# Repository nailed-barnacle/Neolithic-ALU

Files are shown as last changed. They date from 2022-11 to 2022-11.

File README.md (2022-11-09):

# Neolithic-ALU
This is a simple 8-bit ALU based on Ken Shirriff's dissection of the 8085's ALU at https://www.righto.com/2013/01/inside-alu-of-8085-microprocessor.html

It takes two inputs - A and B - and a number of control inputs to provide an output, one of:
- A (bypass)
- A OR B
- A AND B
- A XOR B
- A plus B with carry
- A minus B with carry 
- Complement of B
- A shifted right

Notes:

The carry input and output for arithmetic operations is inverted. To add or subtract without carry, it must be set. For other logic operations it must be set or cleared.

The zero output is inverted (i.e. set if the output is not zero).

The sign output is simply bit 7 of the result.

The bit shifted out after a right shift is the lowest input bit; it has no dedicated output. A dedicated input - shift_in - provides the high bit of the shift result.

At the time of posting, the only parts available for all components were 74HC; the circuit will operate across the 74HC range but will be faster at 5v than 3v3. I still need to measure the propagation delay but expect it to be around 60-70ns at five volts. Other equivalant parts - e.g. AHC or VLC - will probably be faster. The critical path is the chain of OR gates running right to left through the circuit.

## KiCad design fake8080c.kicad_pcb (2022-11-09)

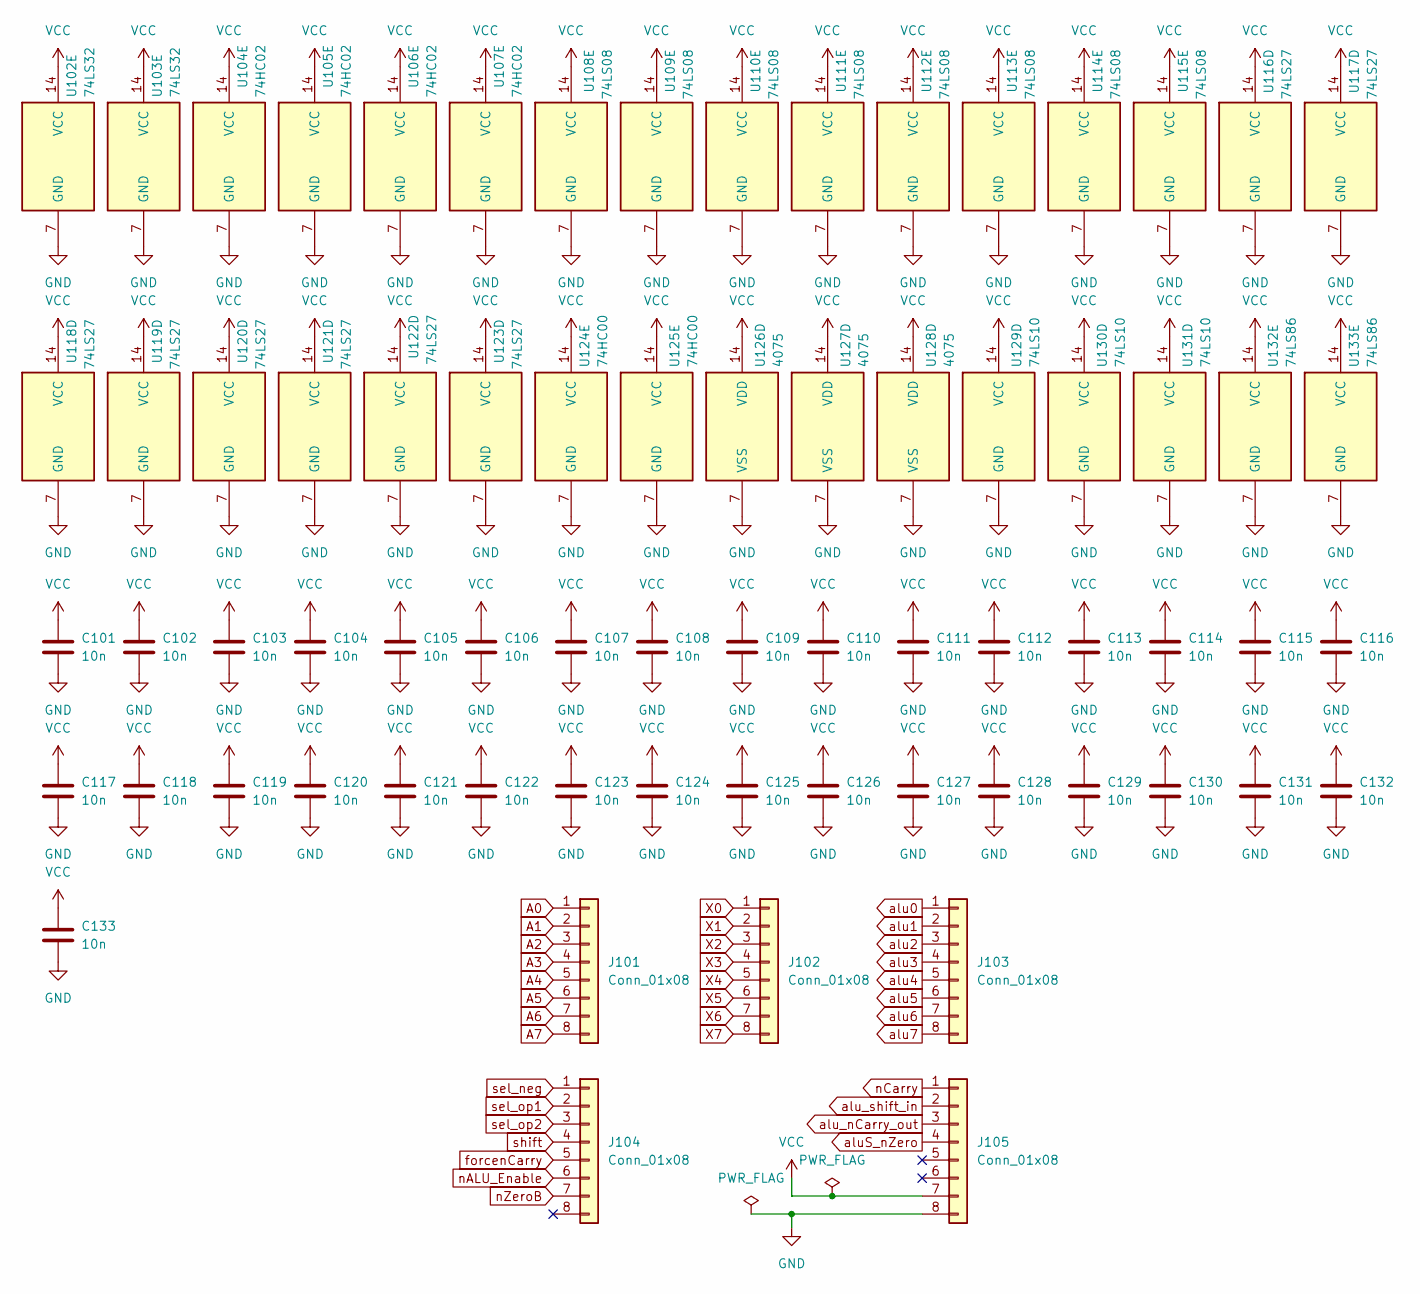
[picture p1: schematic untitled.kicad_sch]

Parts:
C101, C102, C103, C104, C105, C106, C107, C108, C109, C110, C111, C112, C113, C114, C115, C116, C117, C118, C119, C120, C121, C122, C123, C124, C125, C126, C127, C128, C129, C130, C131, C132, C133: 10n; C_0603_1608Metric
J101, J102, J103, J104, J105: Conn_01x08; PinHeader_1x08_P2.54mm_Vertical
U102, U103: 74LS32; SOIC-14_3.9x8.7mm_P1.27mm
U104, U105, U106, U107: 74HC02; SOIC-14_3.9x8.7mm_P1.27mm
U108, U109, U110, U111, U112, U113, U114, U115: 74LS08; SOIC-14_3.9x8.7mm_P1.27mm
U116, U117, U118, U119, U120, U121, U122, U123: 74LS27; SOIC-14_3.9x8.7mm_P1.27mm
U124, U125: 74HC00; SOIC-14_3.9x8.7mm_P1.27mm
U126, U127, U128: 4075; SOIC-14_3.9x8.7mm_P1.27mm
U129, U130, U131: 74LS10; SOIC-14_3.9x8.7mm_P1.27mm
U132, U133: 74LS86; SOIC-14_3.9x8.7mm_P1.27mm

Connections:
A0: J101.1; also elsewhere on the board
A1: J101.2; also elsewhere on the board
A2: J101.3; also elsewhere on the board
A3: J101.4; also elsewhere on the board
A4: J101.5; also elsewhere on the board
A5: J101.6; also elsewhere on the board
A6: J101.7; also elsewhere on the board
A7: J101.8; also elsewhere on the board
GND: C101.2, C102.2, C103.2, C104.2, C105.2, C106.2, C107.2, C108.2, C109.2, C110.2, C111.2, C112.2, C113.2, C114.2, C115.2, C116.2, C117.2, C118.2, C119.2, C120.2, C121.2, C122.2, C123.2, C124.2, C125.2, C126.2, C127.2, C128.2, C129.2, C130.2, C131.2, C132.2, C133.2, J105.8, U102.7 (GND), U103.7 (GND), U104.7 (GND), U105.7 (GND), U106.7 (GND), U107.7 (GND), U108.7 (GND), U109.7 (GND), U110.7 (GND), U111.7 (GND), U112.7 (GND), U113.7 (GND), U114.7 (GND), U115.7 (GND), U116.7 (GND), U117.7 (GND), U118.7 (GND), U119.7 (GND), U120.7 (GND), U121.7 (GND), U122.7 (GND), U123.7 (GND), U124.7 (GND), U125.7 (GND), U126.7 (VSS), U127.7 (VSS), U128.7 (VSS), U129.7 (GND), U130.7 (GND), U131.7 (GND), U132.7 (GND), U133.7 (GND); also elsewhere on the board
VCC: C101.1, C102.1, C103.1, C104.1, C105.1, C106.1, C107.1, C108.1, C109.1, C110.1, C111.1, C112.1, C113.1, C114.1, C115.1, C116.1, C117.1, C118.1, C119.1, C120.1, C121.1, C122.1, C123.1, C124.1, C125.1, C126.1, C127.1, C128.1, C129.1, C130.1, C131.1, C132.1, C133.1, J105.7, U102.14 (VCC), U103.14 (VCC), U104.14 (VCC), U105.14 (VCC), U106.14 (VCC), U107.14 (VCC), U108.14 (VCC), U109.14 (VCC), U110.14 (VCC), U111.14 (VCC), U112.14 (VCC), U113.14 (VCC), U114.14 (VCC), U115.14 (VCC), U116.14 (VCC), U117.14 (VCC), U118.14 (VCC), U119.14 (VCC), U120.14 (VCC), U121.14 (VCC), U122.14 (VCC), U123.14 (VCC), U124.14 (VCC), U125.14 (VCC), U126.14 (VDD), U127.14 (VDD), U128.14 (VDD), U129.14 (VCC), U130.14 (VCC), U131.14 (VCC), U132.14 (VCC), U133.14 (VCC); also elsewhere on the board
X0: J102.1; also elsewhere on the board
X1: J102.2; also elsewhere on the board
X2: J102.3; also elsewhere on the board
X3: J102.4; also elsewhere on the board
X4: J102.5; also elsewhere on the board
X5: J102.6; also elsewhere on the board
X6: J102.7; also elsewhere on the board
X7: J102.8; also elsewhere on the board
alu0: J103.1; also elsewhere on the board
alu1: J103.2; also elsewhere on the board
alu2: J103.3; also elsewhere on the board
alu3: J103.4; also elsewhere on the board
alu4: J103.5; also elsewhere on the board
alu5: J103.6; also elsewhere on the board
alu6: J103.7; also elsewhere on the board
alu7: J103.8; also elsewhere on the board
aluS_nZero: J105.4; also elsewhere on the board
alu_nCarry_out: J105.3; also elsewhere on the board
alu_shift_in: J105.2; also elsewhere on the board
forcenCarry: J104.5; also elsewhere on the board
nALU_Enable: J104.6; also elsewhere on the board
nCarry: J105.1; also elsewhere on the board
nZeroB: J104.7; also elsewhere on the board
sel_neg: J104.1; also elsewhere on the board
sel_op1: J104.2; also elsewhere on the board
sel_op2: J104.3; also elsewhere on the board
shift: J104.4; also elsewhere on the board

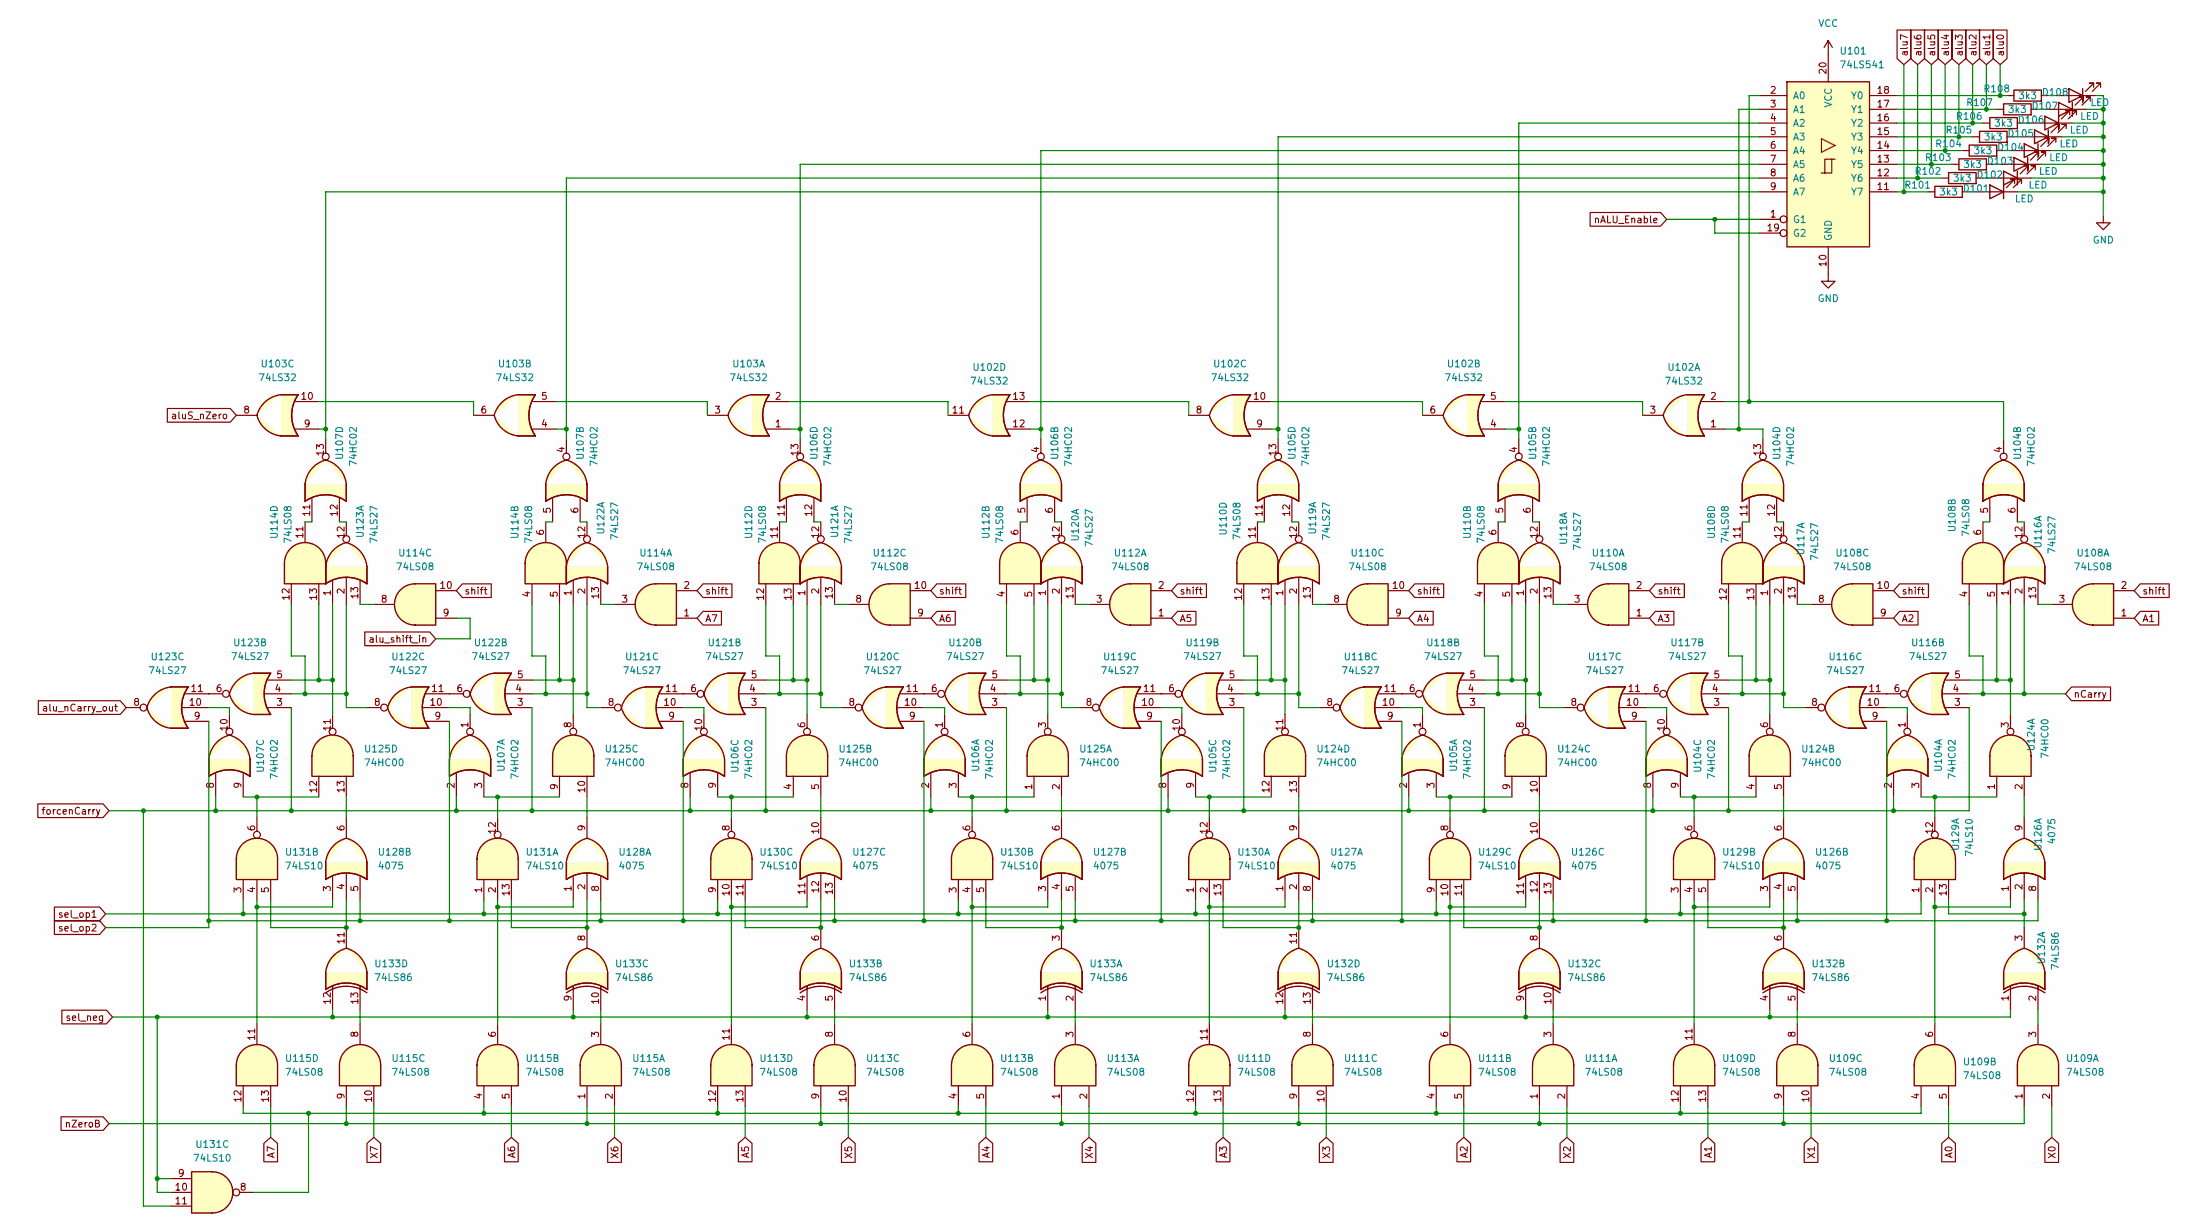
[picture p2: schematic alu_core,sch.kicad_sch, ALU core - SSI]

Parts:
D101, D102, D103, D104, D105, D106, D107, D108: LED; LED_0603_1608Metric_Pad1.05x0.95mm_HandSolder
R101, R102, R103, R104, R105, R106, R107, R108: 3k3; R_0603_1608Metric_Pad0.98x0.95mm_HandSolder
U101: 74LS541; SOIC-20W_7.5x12.8mm_P1.27mm
U102, U103: 74LS32; SOIC-14_3.9x8.7mm_P1.27mm
U104, U105, U106, U107: 74HC02; SOIC-14_3.9x8.7mm_P1.27mm
U108, U109, U110, U111, U112, U113, U114, U115: 74LS08; SOIC-14_3.9x8.7mm_P1.27mm
U116, U117, U118, U119, U120, U121, U122, U123: 74LS27; SOIC-14_3.9x8.7mm_P1.27mm
U124, U125: 74HC00; SOIC-14_3.9x8.7mm_P1.27mm
U126, U127, U128: 4075; SOIC-14_3.9x8.7mm_P1.27mm
U129, U130, U131: 74LS10; SOIC-14_3.9x8.7mm_P1.27mm
U132, U133: 74LS86; SOIC-14_3.9x8.7mm_P1.27mm

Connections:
A0: U109.5; also elsewhere on the board
A1: U108.1, U109.13; also elsewhere on the board
A2: U108.9, U111.5; also elsewhere on the board
A3: U110.1, U111.13; also elsewhere on the board
A4: U110.9, U113.5; also elsewhere on the board
A5: U112.1, U113.13; also elsewhere on the board
A6: U112.9, U115.5; also elsewhere on the board
A7: U114.1, U115.13; also elsewhere on the board
GND: D101.1 (K), D102.1 (K), D103.1 (K), D104.1 (K), D105.1 (K), D106.1 (K), D107.1 (K), D108.1 (K), U101.10 (GND); also elsewhere on the board
unnamed: D108.2 (A), R108.2
unnamed: D101.2 (A), R101.2
unnamed: D102.2 (A), R102.2
unnamed: D103.2 (A), R103.2
unnamed: D104.2 (A), R104.2
unnamed: D105.2 (A), R105.2
unnamed: D106.2 (A), R106.2
unnamed: D107.2 (A), R107.2
unnamed: U101.2 (A0), U102.2, U104.4
unnamed: U101.3 (A1), U102.1, U104.13
unnamed: U101.4 (A2), U102.4, U105.4
unnamed: U101.5 (A3), U102.9, U105.13
unnamed: U101.6 (A4), U102.12, U106.4
unnamed: U101.7 (A5), U103.1, U106.13
unnamed: U101.8 (A6), U103.4, U107.4
unnamed: U101.9 (A7), U103.9, U107.13
unnamed: U102.3, U102.5
unnamed: U102.6, U102.10
unnamed: U102.8, U102.13
unnamed: U102.11, U103.2
unnamed: U103.3, U103.5
unnamed: U103.6, U103.10
unnamed: U104.1, U116.10
unnamed: U104.3, U124.1, U129.12
unnamed: U104.5, U108.6
unnamed: U104.6, U116.12
unnamed: U104.9, U124.4, U129.6
unnamed: U104.10, U117.10
unnamed: U104.11, U108.11
unnamed: U104.12, U117.12
unnamed: U105.5, U110.6
unnamed: U105.6, U118.12
unnamed: U105.9, U124.12, U130.12
unnamed: U105.10, U119.10
unnamed: U105.11, U110.11
unnamed: U105.12, U119.12
unnamed: U106.1, U120.10
unnamed: U106.3, U125.1, U130.6
unnamed: U106.5, U112.6
unnamed: U106.6, U120.12
unnamed: U106.9, U125.4, U130.8
unnamed: U106.10, U121.10
unnamed: U106.11, U112.11
unnamed: U106.12, U121.12
unnamed: U107.1, U122.10
unnamed: U107.3, U125.9, U131.12
unnamed: U107.5, U114.6
unnamed: U107.6, U122.12
unnamed: U107.9, U125.12, U131.6
unnamed: U107.10, U123.10
unnamed: U107.11, U114.11
unnamed: U107.12, U123.12
unnamed: U108.3, U116.13
unnamed: U108.5, U116.1, U116.5, U124.3
unnamed: U108.8, U117.13
unnamed: U108.12, U116.8, U117.2, U117.4
unnamed: U108.13, U117.1, U117.5, U124.6
unnamed: U109.3, U132.2
unnamed: U109.4, U109.12, U111.4, U111.12, U113.4, U113.12, U115.4, U115.12, U131.8
unnamed: U109.6, U126.1, U129.2
unnamed: U109.8, U132.5
unnamed: U109.11, U126.3, U129.4
unnamed: U110.3, U118.13
unnamed: U110.4, U117.8, U118.2, U118.4
unnamed: U110.5, U118.1, U118.5, U124.8
unnamed: U110.8, U119.13
unnamed: U110.12, U118.8, U119.2, U119.4
unnamed: U110.13, U119.1, U119.5, U124.11
unnamed: U111.3, U132.10
unnamed: U111.6, U126.11, U129.10
unnamed: U111.8, U132.13
unnamed: U111.11, U127.1, U130.2
unnamed: U112.3, U120.13
unnamed: U112.4, U119.8, U120.2, U120.4
unnamed: U112.5, U120.1, U120.5, U125.3
unnamed: U112.8, U121.13
unnamed: U112.12, U120.8, U121.2, U121.4
unnamed: U112.13, U121.1, U121.5, U125.6
unnamed: U113.3, U133.2
unnamed: U113.6, U127.3, U130.4
unnamed: U113.8, U133.5
unnamed: U113.11, U127.11, U130.10
unnamed: U114.3, U122.13
unnamed: U114.4, U121.8, U122.2, U122.4
unnamed: U114.5, U122.1, U122.5, U125.8
unnamed: U114.8, U123.13
unnamed: U114.12, U122.8, U123.2, U123.4
unnamed: U114.13, U123.1, U123.5, U125.11
unnamed: U115.3, U133.10
unnamed: U115.6, U128.1, U131.2
unnamed: U115.8, U133.13
unnamed: U115.11, U128.3, U131.4
unnamed: U116.6, U116.11
unnamed: U117.6, U117.11
unnamed: U118.6, U118.11
unnamed: U105.1, U118.10
unnamed: U119.6, U119.11
unnamed: U120.6, U120.11
unnamed: U121.6, U121.11
unnamed: U122.6, U122.11
unnamed: U123.6, U123.11
unnamed: U124.2, U126.9
unnamed: U124.5, U126.6
unnamed: U105.3, U124.9, U129.8
unnamed: U124.10, U126.10
unnamed: U124.13, U127.9
unnamed: U125.2, U127.6
unnamed: U125.5, U127.10
unnamed: U125.10, U128.9
unnamed: U125.13, U128.6
unnamed: U126.2, U129.13, U132.3
unnamed: U126.4, U129.5, U132.6
unnamed: U126.12, U129.11, U132.8
unnamed: U127.2, U130.13, U132.11
unnamed: U127.12, U130.11, U133.6
unnamed: U128.4, U131.5, U133.11
unnamed: U127.4, U130.5, U133.3
unnamed: U128.2, U131.13, U133.8
VCC: U101.20 (VCC); also elsewhere on the board
X0: U109.2; also elsewhere on the board
X1: U109.10; also elsewhere on the board
X2: U111.2; also elsewhere on the board
X3: U111.10; also elsewhere on the board
X4: U113.2; also elsewhere on the board
X5: U113.10; also elsewhere on the board
X6: U115.2; also elsewhere on the board
X7: U115.10; also elsewhere on the board
alu0: R108.1, U101.18 (Y0); also elsewhere on the board
alu1: R107.1, U101.17 (Y1); also elsewhere on the board
alu2: R106.1, U101.16 (Y2); also elsewhere on the board
alu3: R105.1, U101.15 (Y3); also elsewhere on the board
alu4: R104.1, U101.14 (Y4); also elsewhere on the board
alu5: R103.1, U101.13 (Y5); also elsewhere on the board
alu6: R102.1, U101.12 (Y6); also elsewhere on the board
alu7: R101.1, U101.11 (Y7); also elsewhere on the board
aluS_nZero: U103.8; also elsewhere on the board
alu_nCarry_out: U123.8; also elsewhere on the board
alu_shift_in: U114.9; also elsewhere on the board
forcenCarry: U104.2, U104.8, U105.2, U105.8, U106.2, U106.8, U107.2, U107.8, U116.3, U117.3, U118.3, U119.3, U120.3, U121.3, U122.3, U123.3, U131.11; also elsewhere on the board
nALU_Enable: U101.1 (G1), U101.19 (G2); also elsewhere on the board
nCarry: U108.4, U116.2, U116.4; also elsewhere on the board
nZeroB: U109.1, U109.9, U111.1, U111.9, U113.1, U113.9, U115.1, U115.9; also elsewhere on the board
sel_neg: U131.9, U131.10, U132.1, U132.4, U132.9, U132.12, U133.1, U133.4, U133.9, U133.12; also elsewhere on the board
sel_op1: U129.1, U129.3, U129.9, U130.1, U130.3, U130.9, U131.1, U131.3; also elsewhere on the board
sel_op2: U116.9, U117.9, U118.9, U119.9, U120.9, U121.9, U122.9, U123.9, U126.5, U126.8, U126.13, U127.5, U127.8, U127.13, U128.5, U128.8; also elsewhere on the board
shift: U108.2, U108.10, U110.2, U110.10, U112.2, U112.10, U114.2, U114.10; also elsewhere on the board

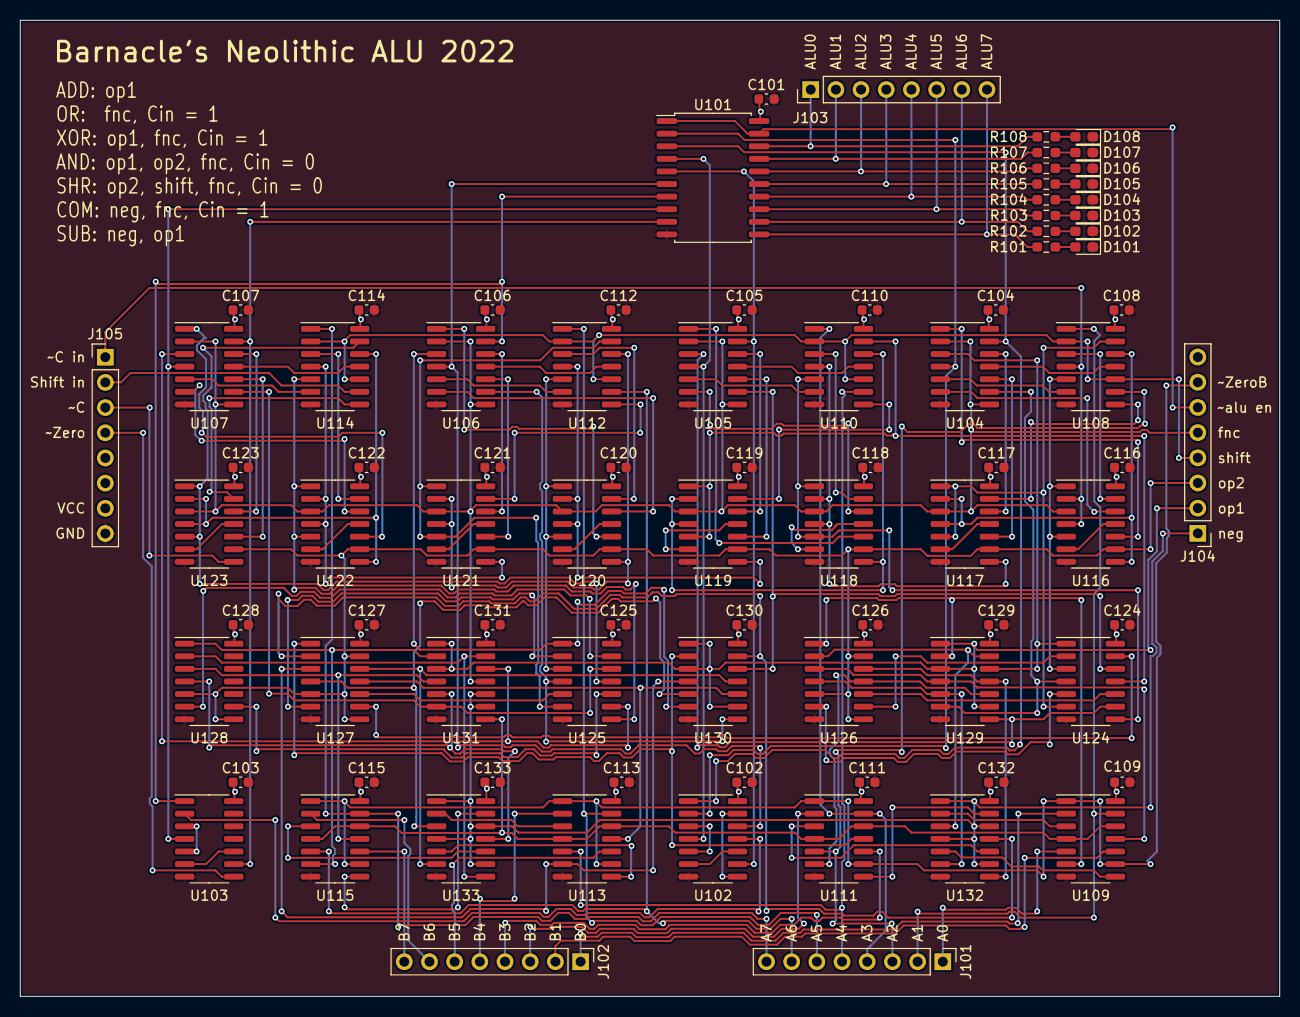
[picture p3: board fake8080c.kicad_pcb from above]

Board: 2 copper layers, 127.0 x 98.4 mm, 87 parts (0 on the bottom side), 155 nets.
